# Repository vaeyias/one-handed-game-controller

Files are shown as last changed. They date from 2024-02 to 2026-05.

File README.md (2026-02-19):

![Offical github repo (PCBs are here)] https://github.com/MIT-Assistive-Technology/one-handed-game-controller
# :video_game: **One-Handed Game Controller (Left-Handed)**

## 🛠️ **Tools and Materials**
- 3D Printer
- Soldering Kit
- 1 Arduino Micro 
- 2 Thumb Joysticks (KY-023)
- 16 Two-Pin Buttons
- Electrical Wire Cables
- PLA
- 1 ¾ in machine screws size 2-56
- (optional) Foam tape

## :memo: **Instructions**
1. Download ___ files
2. 3D print ___ files
4. Print PCB
5. Solder
6. Upload code to the Arduino
7. Assemble
8. TO DO

## :mag_right: Problem Statement
**Modern game controllers do not accommodate for one-handed users.**

After a stroke or injury, a person may lose some function in their body. Recreational products for the public are often made with the assumption that a person has full control of their body, which means that after permanent injuries, a person may become limited in their choice of hobbies.

Our codesigner, Susan Bibbins, suffers from chronic pain from fibromyalgia and has limited function in her right hand. She always wanted to play video games; however, modern controllers do not accomodate one-handed users.

Our team aims to develop a comfortable and accessible game controller designed specifically for one-handed users so that our codesigner can finally play video games that she has always wanted to try.

## 🔗 References




## ✍️ Acknowledgements
To be completed

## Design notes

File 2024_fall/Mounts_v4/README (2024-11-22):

Updated top mount holes and fixed thinned out bottom mount.

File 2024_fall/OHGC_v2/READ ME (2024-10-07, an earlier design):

This version has complete front and back of OHGC. Has threaded screw holes, back finger indents, and curved edges.

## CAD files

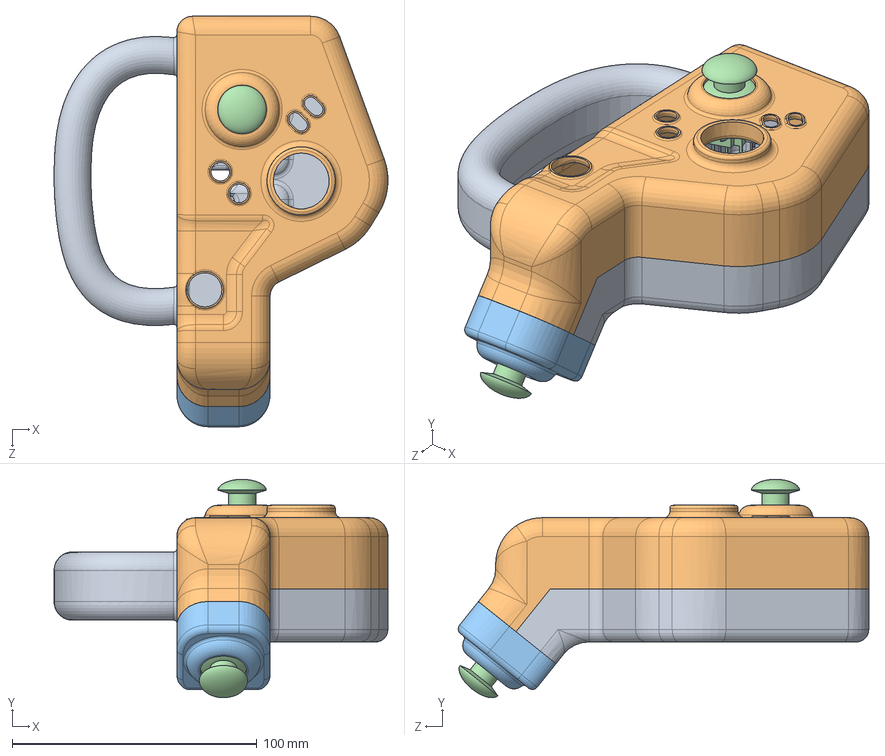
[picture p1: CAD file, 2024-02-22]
2024_spring/solidworks_designs/OHGC_assembly.SLDASM
136.4 x 89.2 x 167.7 mm
OHGC_back
OHGC_front
OHGC_bottom

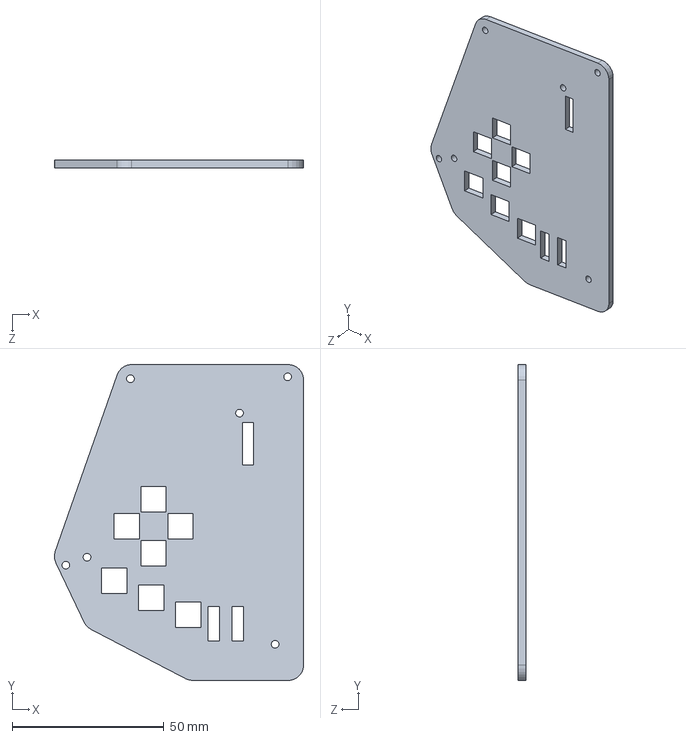
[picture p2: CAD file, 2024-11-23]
2024_fall/OHGC_2.3/Mounts_v4F_Back_Mount_v4.SLDPRT
82.1 x 104.1 x 2.54 mm

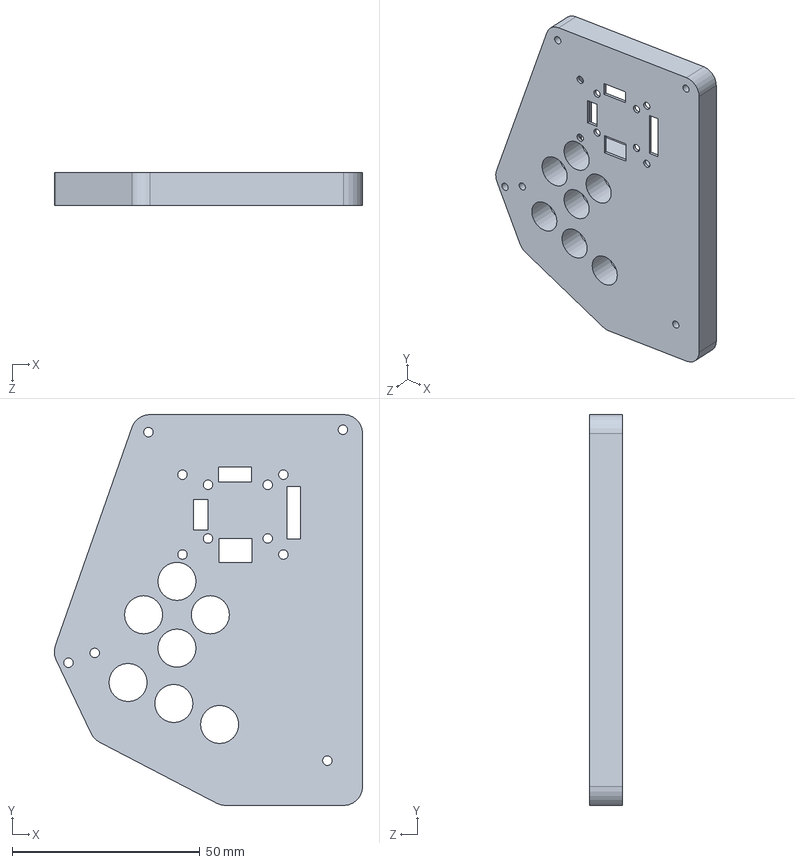
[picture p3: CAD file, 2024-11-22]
2024_fall/OHGC_v2.3/Mounts_v4/F_Front_Mount_v4.SLDPRT
82.1 x 104.1 x 8.89 mm

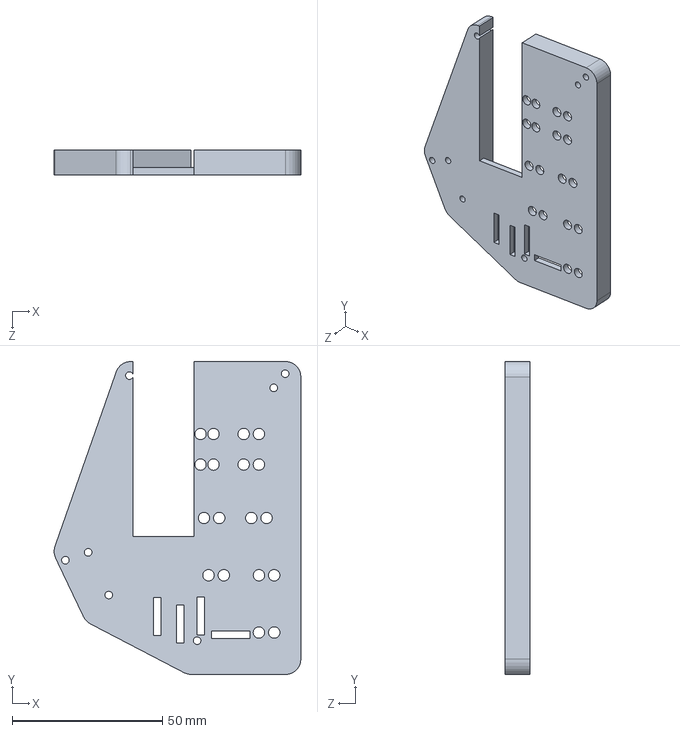
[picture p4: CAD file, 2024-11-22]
2024_fall/OHGC_v2.3/Mounts_v4B_Front_Mount_v4.SLDPRT
82.1 x 104.1 x 8.38 mm

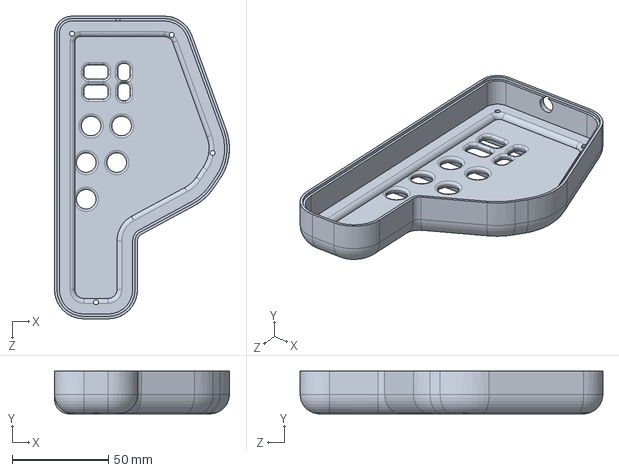
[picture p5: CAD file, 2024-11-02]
2024_fall/PCB Order 3/bottompcb.SLDPRT
91.0 x 22.2 x 157.5 mm

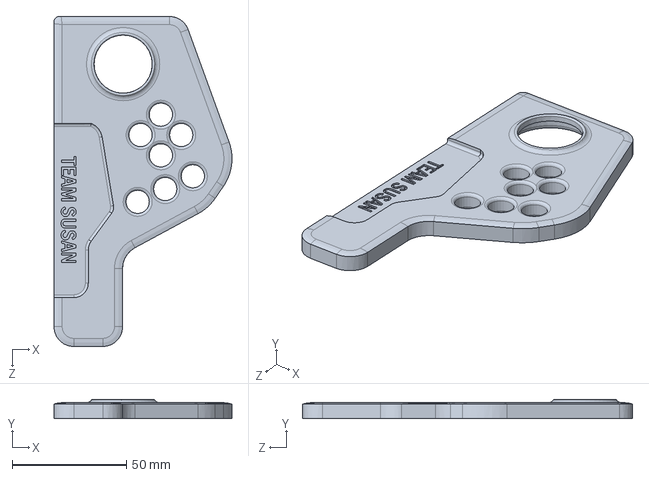
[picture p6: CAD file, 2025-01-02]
2024_fall/Showcase/Reprinted OHGC FRONT for Showcase.SLDPRT
77.8 x 8.45 x 144.3 mm

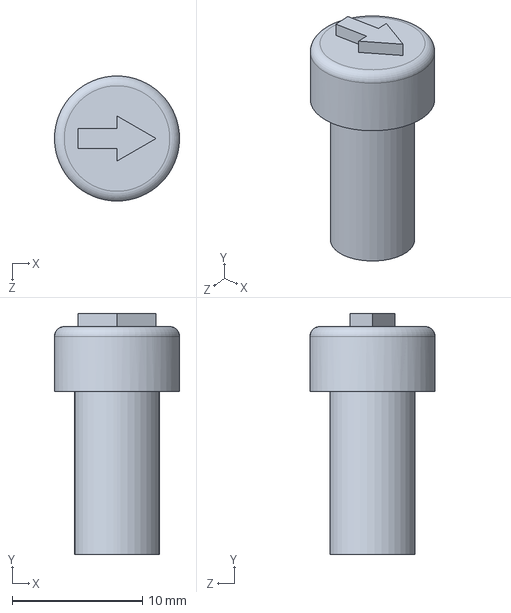
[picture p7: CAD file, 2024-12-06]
2024_spring/solidworks_designs/Button_Updated/DPADbutton.v3.SLDPRT
9.60 x 18.5 x 9.60 mm

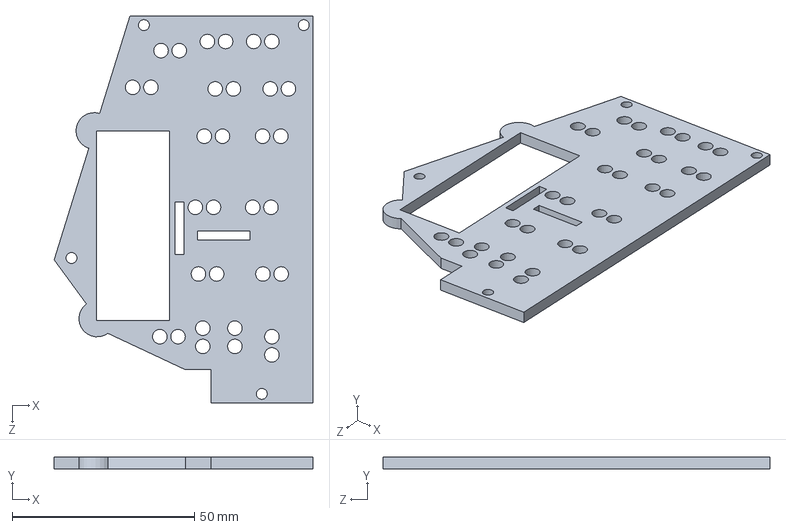
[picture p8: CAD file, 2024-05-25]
2024_spring/solidworks_designs/Mount_Updated_4-28-24.SLDPRT
71.0 x 3.17 x 106.2 mm

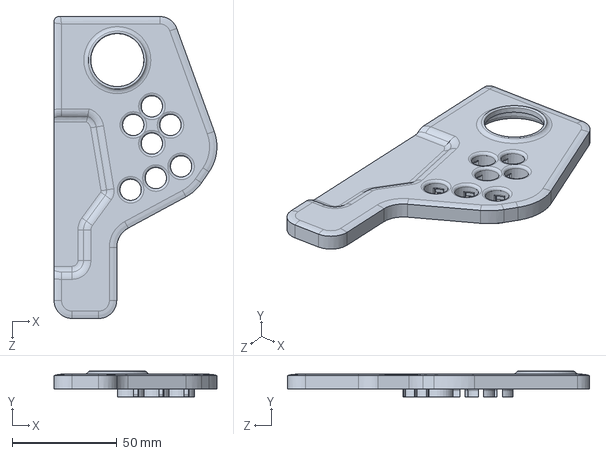
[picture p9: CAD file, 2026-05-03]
2026_spring/SLDPRT-Files/Front_Face.SLDPRT
77.8 x 12.3 x 144.3 mm

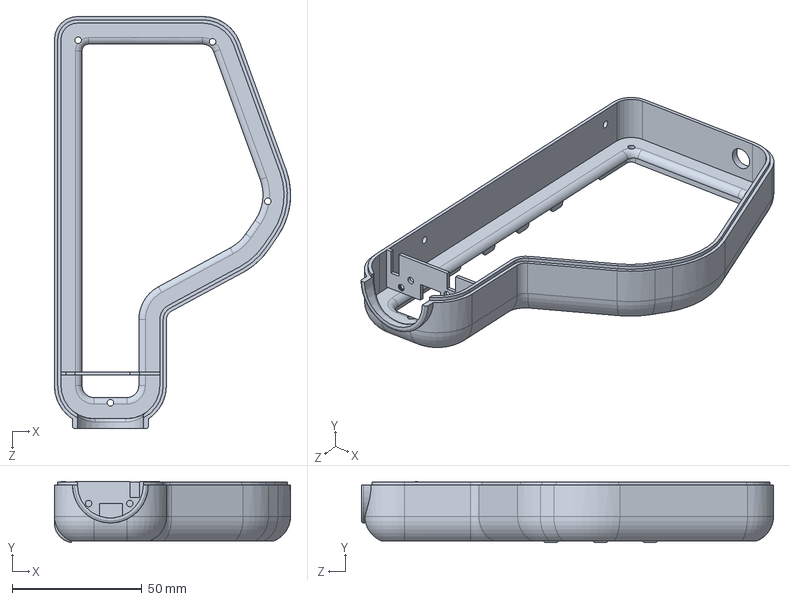
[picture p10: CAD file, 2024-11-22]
2024_fall/OHGC_v2.3/OHGC_BOTTOM_SIDEv2.3.SLDPRT
91.0 x 23.6 x 158.8 mm

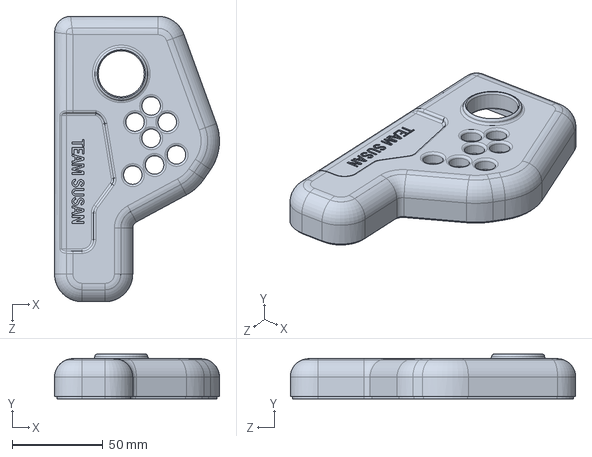
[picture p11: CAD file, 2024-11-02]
2024_fall/PCB Order 3/front_pcb.SLDPRT
91.0 x 24.8 x 157.5 mm

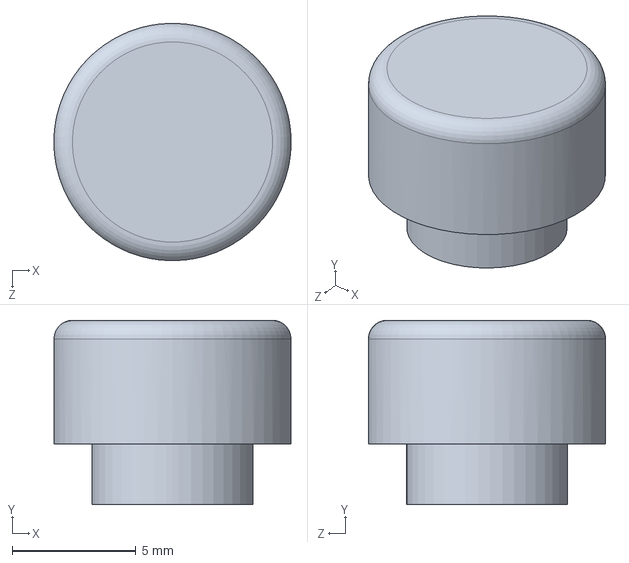
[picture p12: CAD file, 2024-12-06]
2024_spring/solidworks_designs/Button_Updated/bottom_button.v2.5.SLDPRT
9.59 x 7.46 x 9.60 mm

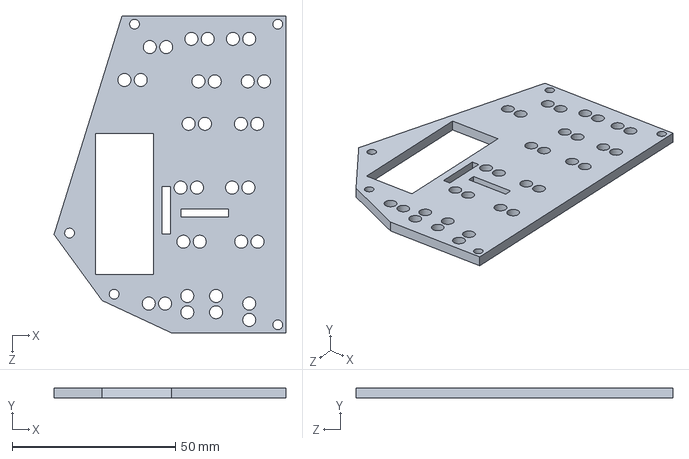
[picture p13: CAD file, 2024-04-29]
2024_spring/solidworks_designs/Mount_Updated_4-26-24.SLDPRT
71.0 x 3.17 x 97.0 mm

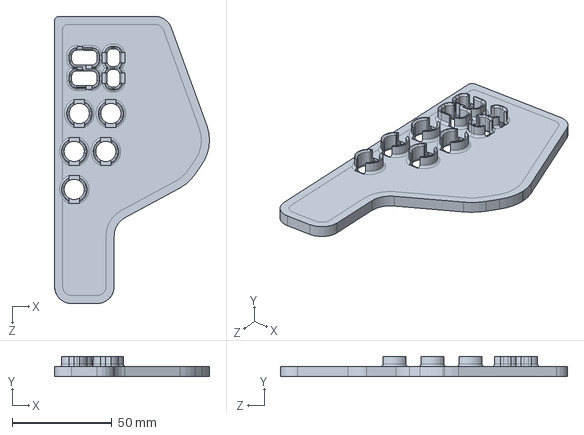
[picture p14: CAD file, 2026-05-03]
2026_spring/SLDPRT-Files/Back_Face.SLDPRT
77.8 x 10.2 x 144.3 mm

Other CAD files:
OHGC-Open-Source-Files/OHGC-SLDPRT-Files/Front_Face.SLDPRT
OHGC-Open-Source-Files/OHGC-STL-Files/F_Back_Mount_v4.1.STL
2024_fall/OHGC_v2.3/Mounts_v4/B_Back_Mount_v4.SLDPRT
2024_fall/Showcase/OHGC_BOTTOM_SIDEv2.4 FINAL.SLDPRT
2024_fall/OHGC_v1/Buttons/DPadButton_v1.SLDPRT
2024_fall/OHGC_v1/Buttons/HomeButton_v1.SLDPRT
2024_fall/OHGC_v1/Buttons/OvalButton_v1.SLDPRT
2024_fall/OHGC_v1/Buttons/PlayButton_v1.SLDPRT
2024_fall/OHGC_v1/Buttons/SelectButton_v1.SLDPRT
2024_fall/OHGC_v1/Mounts/MountPrint1.SLDPRT
2024_fall/OHGC_v1/Mounts/bottom_mount.v1.SLDPRT
2024_fall/OHGC_v1/Mounts/bottom_mount.v2.SLDPRT
2024_fall/OHGC_v1/OHGC BACK.SLDPRT
2024_fall/OHGC_v1/OHGC BACK.STL
2024_fall/OHGC_v1/OHGC BASE_SKETCH.SLDPRT
2024_fall/OHGC_v1/OHGC FRONT.SLDPRT
2024_fall/OHGC_v1/OHGC_BOTTOM_SIDE.SLDPRT
2024_fall/OHGC_v1/OHGC_BOTTOM_SIDE.STL
2024_fall/OHGC_v1/OHGC_FRONT_SIDE.SLDPRT
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

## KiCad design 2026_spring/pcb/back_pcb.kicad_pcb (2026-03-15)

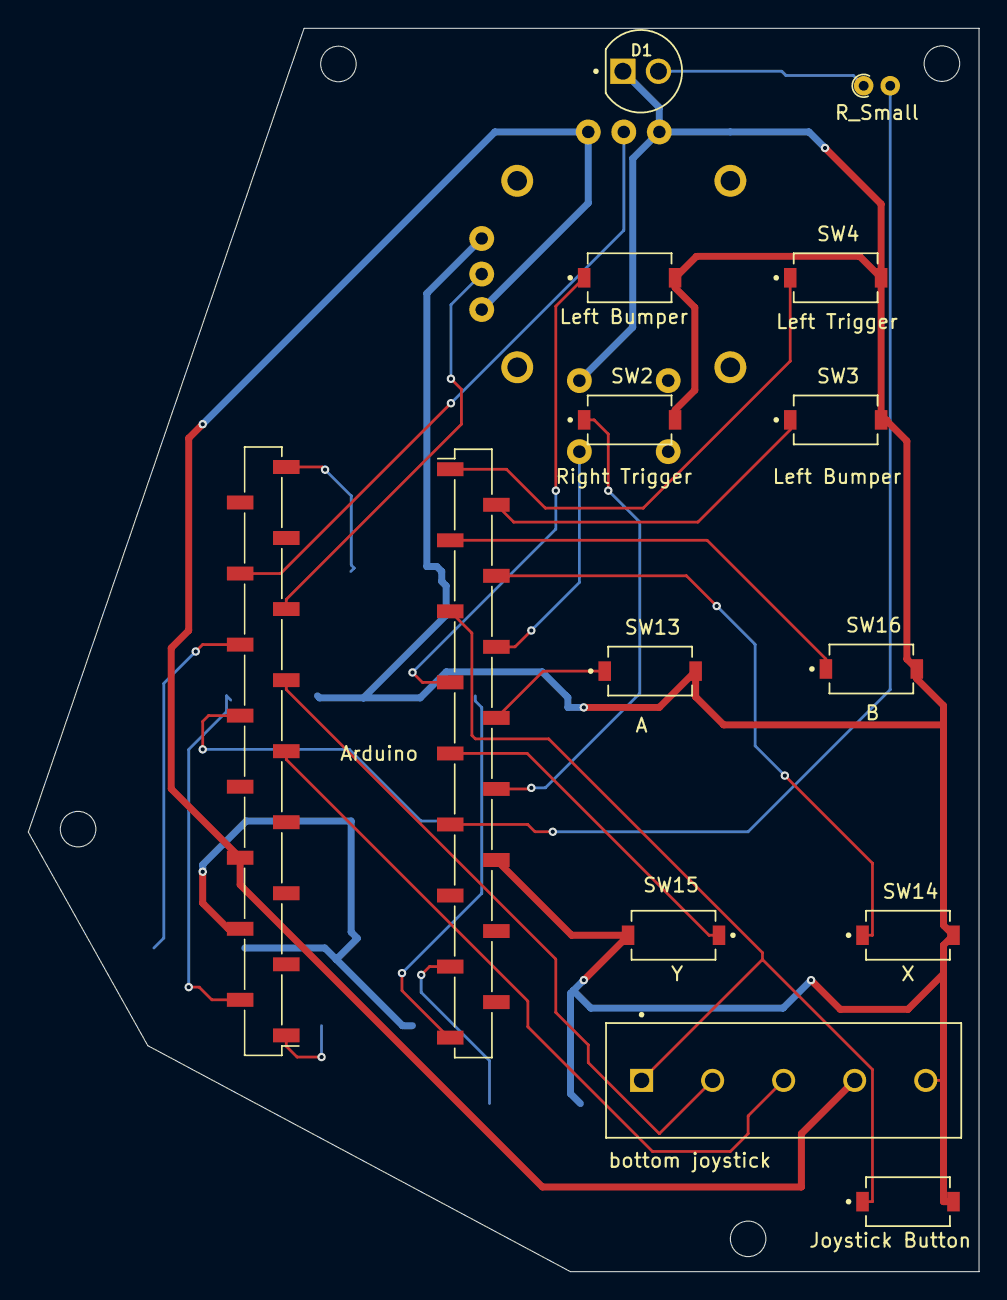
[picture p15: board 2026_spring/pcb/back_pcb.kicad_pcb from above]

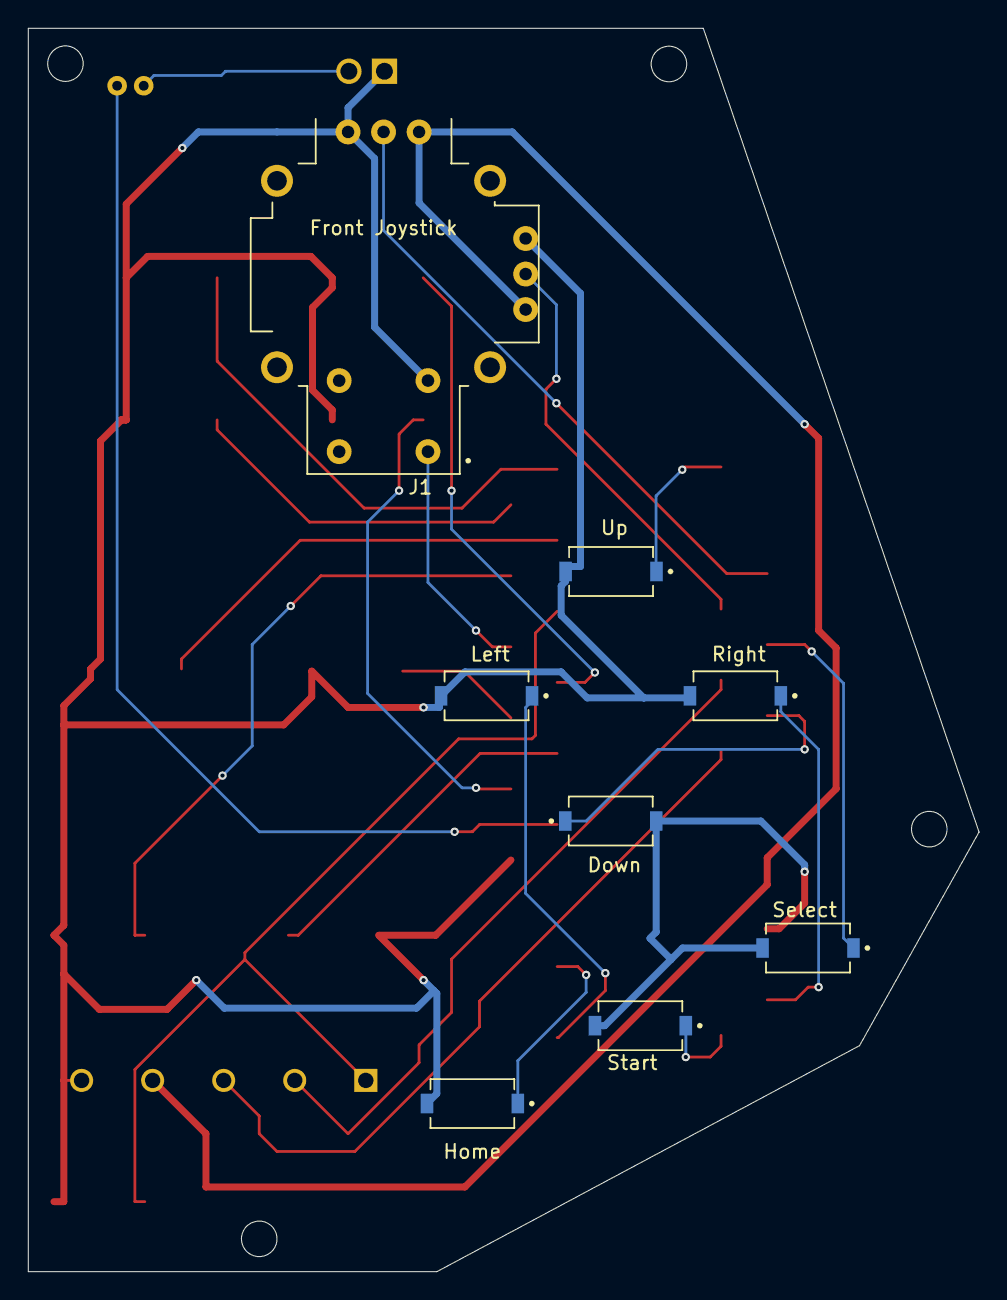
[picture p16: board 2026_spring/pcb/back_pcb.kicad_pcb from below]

Board: 2 copper layers, 68.0 x 88.9 mm, 22 parts (8 on the bottom side), 27 nets.

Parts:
D1: LED; LEDRD254W57D500H1070
J1: Front Joystick; XDCR_COM-09032
J2: bottom joystick; TE_282837-5
J3, J4: Arduino; PinSocket_1x17_P2.54mm_Vertical_SMD_Pin1Left
R1: R_Small; R_Axial_DIN0204_L3.6mm_D1.6mm_P1.90mm_Vertical
SW1: Left Trigger; SW_PTS636_SM43J_SMTR_LFS
SW2: Right Trigger; SW_PTS636_SM43J_SMTR_LFS
SW3, SW4: Left Bumper; SW_PTS636_SM43J_SMTR_LFS
SW5: Up; SW_PTS636_SM43J_SMTR_LFS
SW6: Down; SW_PTS636_SM43J_SMTR_LFS
SW8: Right; SW_PTS636_SM43J_SMTR_LFS
SW9: Left; SW_PTS636_SM43J_SMTR_LFS
SW10: Home; SW_PTS636_SM43J_SMTR_LFS
SW11: Start; SW_PTS636_SM43J_SMTR_LFS
SW13: A; SW_PTS636_SM43J_SMTR_LFS
SW14: X; SW_PTS636_SM43J_SMTR_LFS
SW15: Y; SW_PTS636_SM43J_SMTR_LFS
SW16: B; SW_PTS636_SM43J_SMTR_LFS
SW17: Select; SW_PTS636_SM43J_SMTR_LFS
joy_SW: Joystick Button; SW_PTS636_SM43J_SMTR_LFS

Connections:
/A0: J1.H2, J4.14
/A1: J1.V2, J4.13
/A2: J4.12, SW17.1
/A3: J2.2, J4.11
/A4: J4.10, SW6.1
/A5: J2.3, J4.9
/D1: J3.15, SW10.1
/D2: J3.11, R1.2
/D3: J3.10, SW2.1
/D4: J3.9, SW15.1
/D5: J3.8, SW13.1
/D6: J3.7, SW1.1
/D7: J1.B1A, J3.6
/D8: J2.1, J3.5, joy_SW.1
/D9: J3.4, SW14.1
/D10: J3.3, SW16.1
/D11: J3.2, SW3.1
/D12: J3.1, SW4.1
/D13: J4.17, SW5.1
/D14: J4.2, SW8.1
/D15: J4.1, SW11.1
/D16: J3.17, SW9.1
/GND: D1.GND, J1.B2A, J1.H3, J1.V3, J2.5, J3.12, J4.4, SW1.2, SW2.2, SW3.2, SW4.2, SW5.2, SW6.2, SW8.2, SW9.2, SW10.2, SW11.2, SW13.2, SW14.2, SW15.2, SW16.2, SW17.2, joy_SW.2
/NC: J4.7, J4.8
/R1: D1.R1, R1.1
/RST: J3.13, J4.5
/VCC: J1.H1, J1.V1, J2.4, J4.6

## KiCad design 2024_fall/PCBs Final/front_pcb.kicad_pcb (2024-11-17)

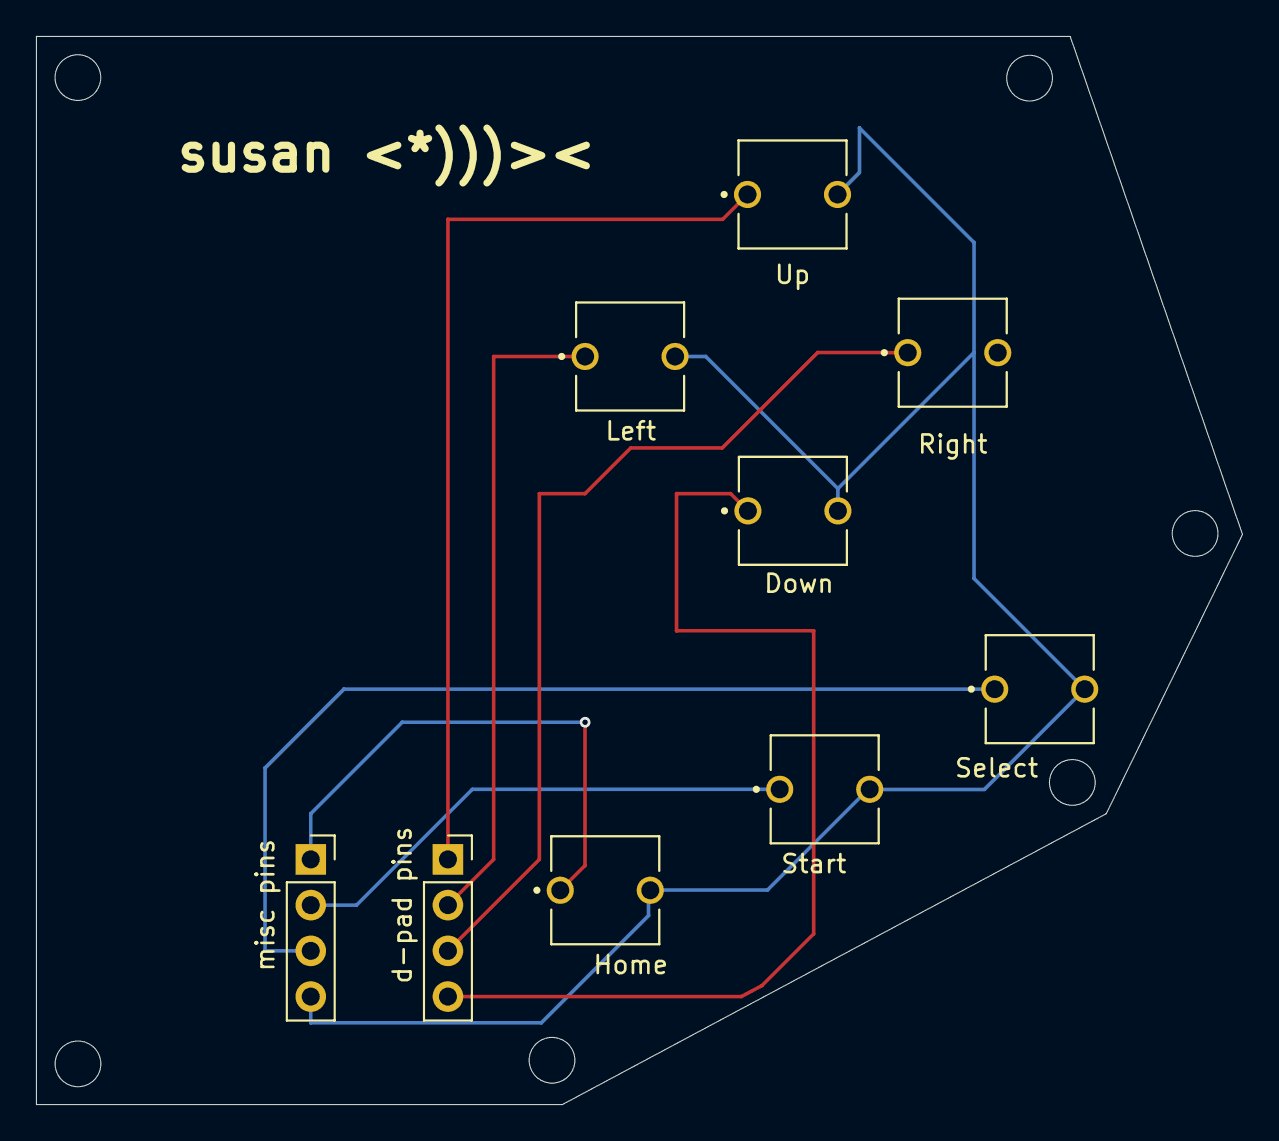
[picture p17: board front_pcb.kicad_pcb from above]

Board: 2 copper layers, 67.0 x 59.3 mm, 9 parts (0 on the bottom side), 8 nets.

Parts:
J1: d-pad pins; PinSocket_1x04_P2.54mm_Vertical
J2: misc pins; PinSocket_1x04_P2.54mm_Vertical
SW1: Up; SW_BUTT-2
SW2: Down; SW_BUTT-2
SW3: Left; SW_BUTT-2
SW4: Right; SW_BUTT-2
SW6: Home; SW_BUTT-2
SW7: Start; SW_BUTT-2
SW8: Select; SW_BUTT-2

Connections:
/D0: J1.1, SW1.1
/D1: J2.3, SW8.1
/D2: J1.2, SW3.1
/D3: J1.3, SW4.1
/D4: J1.4, SW2.1
/D16: J2.1, SW6.1
/D17: J2.2, SW7.1
/GND: J2.4, SW1.2, SW2.2, SW3.2, SW4.2, SW6.2, SW7.2, SW8.2

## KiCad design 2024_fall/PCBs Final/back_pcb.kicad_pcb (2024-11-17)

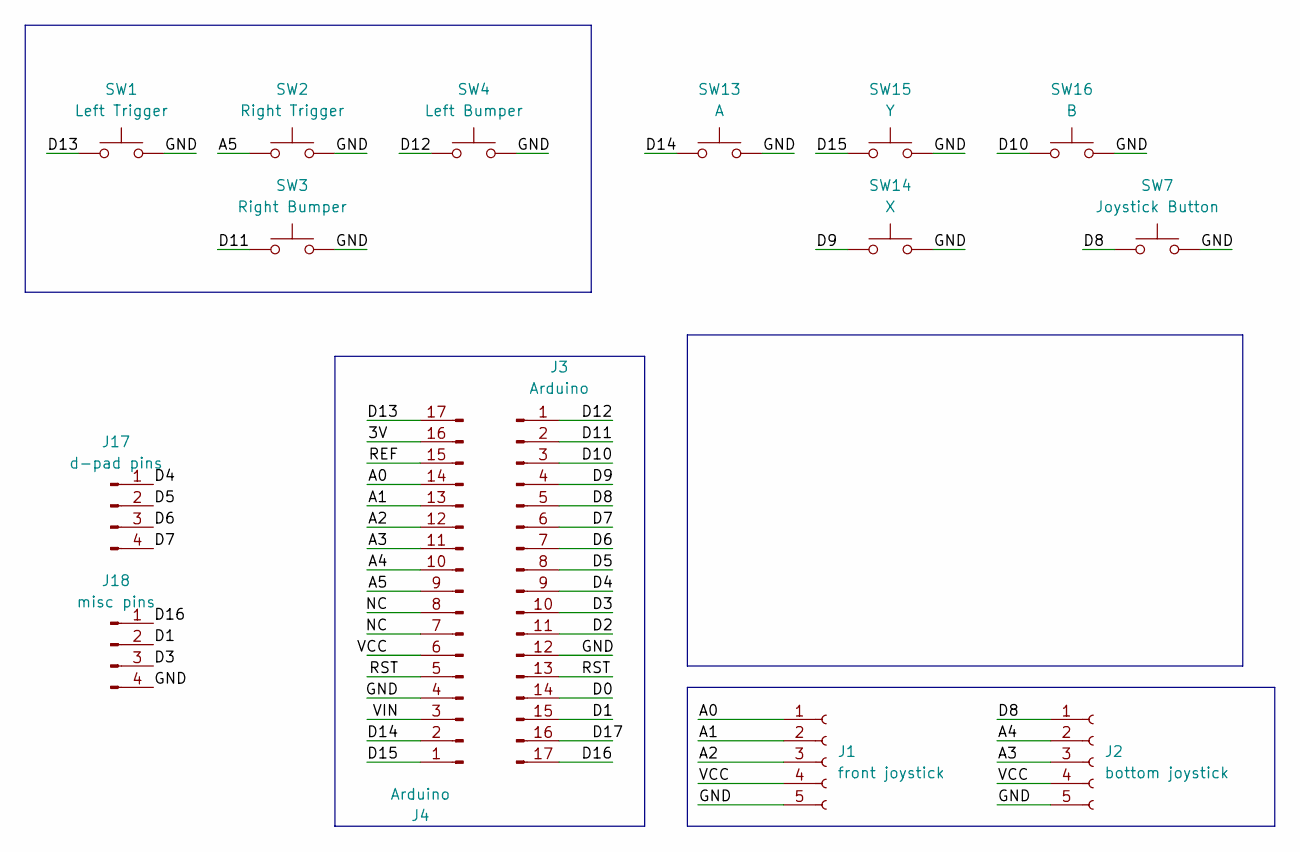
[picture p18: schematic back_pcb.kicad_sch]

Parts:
J1: front joystick; PinSocket_1x05_P2.54mm_Vertical
J2: bottom joystick; PinSocket_1x05_P2.54mm_Vertical
J3, J4: Arduino; PinSocket_1x17_P2.54mm_Vertical
J17: d-pad pins; PinSocket_1x04_P2.54mm_Vertical
J18: misc pins; PinSocket_1x04_P2.54mm_Vertical
SW1: Left Trigger; SW_BUTT-2
SW2: Right Trigger; SW_BUTT-2
SW3: Right Bumper; SW_BUTT-2
SW4: Left Bumper; SW_BUTT-2
SW7: Joystick Button; SW_BUTT-2
SW13: A; SW_BUTT-2
SW14: X; SW_BUTT-2
SW15: Y; SW_BUTT-2
SW16: B; SW_BUTT-2

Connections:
/3V: J4.16
/A0: J1.1, J4.14
/A1: J1.2, J4.13
/A2: J1.3, J4.12
/A3: J2.3, J4.11
/A4: J2.2, J4.10
/A5: J4.9, SW2.1
/D0: J3.14
/D1: J3.15, J18.2
/D2: J3.11
/D3: J3.10, J18.3
/D4: J3.9, J17.1
/D5: J3.8, J17.2
/D6: J3.7, J17.3
/D7: J3.6, J17.4
/D8: J2.1, J3.5, SW7.1
/D9: J3.4, SW14.1
/D10: J3.3, SW16.1
/D11: J3.2, SW3.1
/D12: J3.1, SW4.1
/D13: J4.17, SW1.1
/D14: J4.2, SW13.1
/D15: J4.1, SW15.1
/D16: J3.17, J18.1
/D17: J3.16
/GND: J1.5, J2.5, J3.12, J4.4, J18.4, SW1.2, SW2.2, SW3.2, SW4.2, SW7.2, SW13.2, SW14.2, SW15.2, SW16.2
/NC: J4.7, J4.8
/REF: J4.15
/RST: J3.13, J4.5
/VCC: J1.4, J2.4, J4.6
/VIN: J4.3

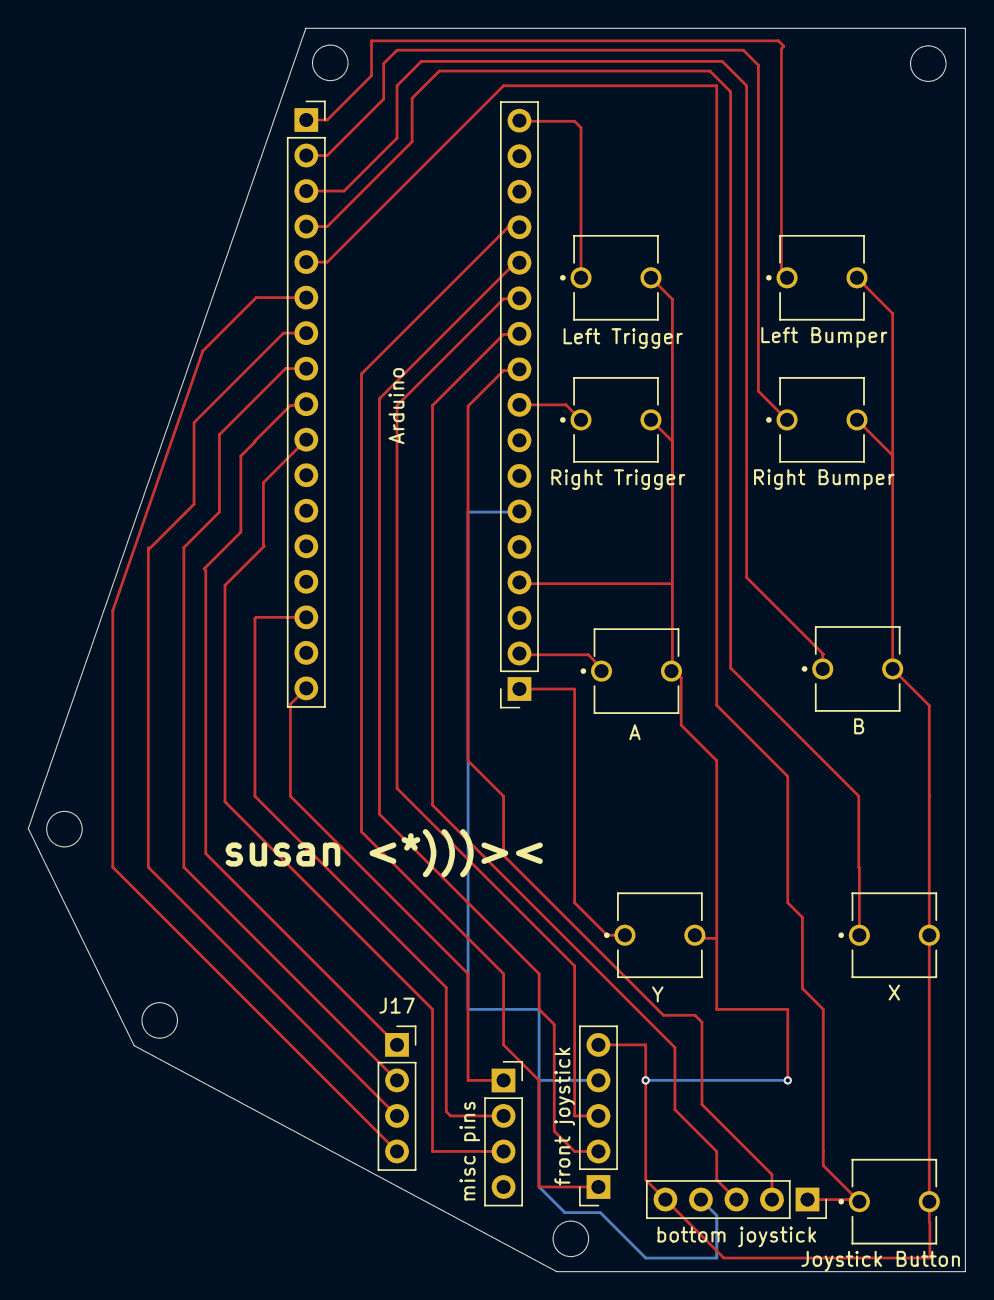
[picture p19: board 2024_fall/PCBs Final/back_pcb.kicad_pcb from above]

Board: 2 copper layers, 67.0 x 88.9 mm, 15 parts (0 on the bottom side), 25 nets.

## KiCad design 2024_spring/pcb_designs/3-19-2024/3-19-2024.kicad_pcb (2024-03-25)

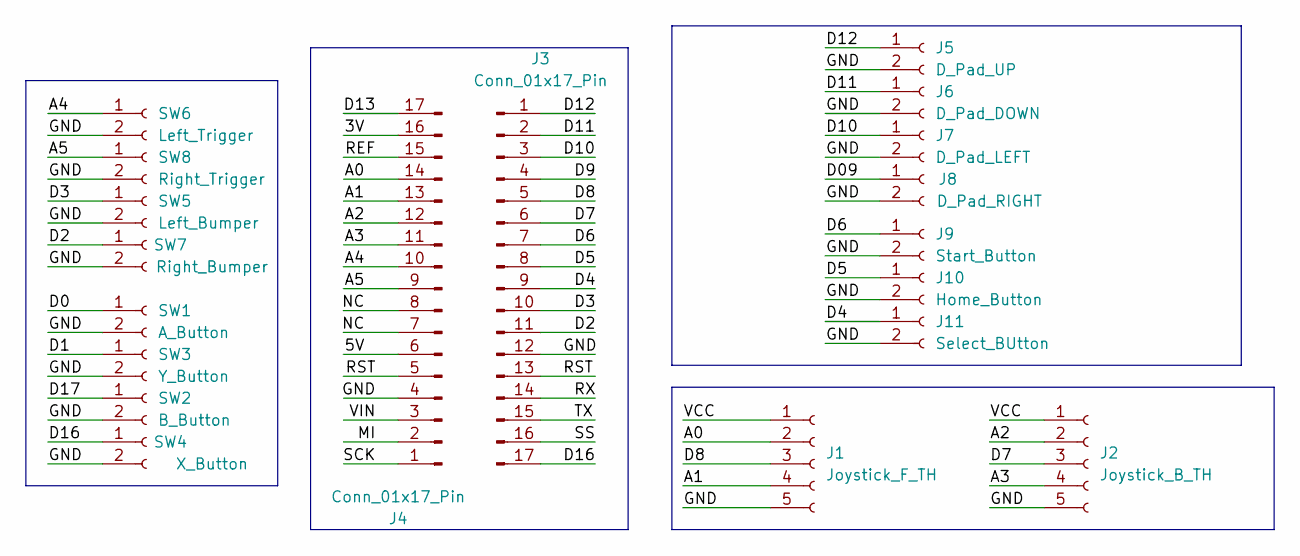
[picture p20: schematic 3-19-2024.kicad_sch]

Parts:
J1: Joystick_F_TH; SolderWire-0.1sqmm_1x05_P3.6mm_D0.4mm_OD1mm
J2: Joystick_B_TH; SolderWire-0.1sqmm_1x05_P3.6mm_D0.4mm_OD1mm
J3, J4: Conn_01x17_Pin; PinSocket_1x17_P2.54mm_Vertical
J5: D_Pad_UP; SolderWire-0.1sqmm_1x02_P3.6mm_D0.4mm_OD1mm
J6: D_Pad_DOWN; SolderWire-0.1sqmm_1x02_P3.6mm_D0.4mm_OD1mm
J7: D_Pad_LEFT; SolderWire-0.1sqmm_1x02_P3.6mm_D0.4mm_OD1mm
J8: D_Pad_RIGHT; SolderWire-0.1sqmm_1x02_P3.6mm_D0.4mm_OD1mm
J9: Start_Button; SolderWire-0.1sqmm_1x02_P3.6mm_D0.4mm_OD1mm
J10: Home_Button; SolderWire-0.1sqmm_1x02_P3.6mm_D0.4mm_OD1mm
J11: Select_BUtton; SolderWire-0.1sqmm_1x02_P3.6mm_D0.4mm_OD1mm
SW1: A_Button; SolderWire-0.1sqmm_1x02_P3.6mm_D0.4mm_OD1mm
SW2: B_Button; SolderWire-0.1sqmm_1x02_P3.6mm_D0.4mm_OD1mm
SW3: Y_Button; SolderWire-0.1sqmm_1x02_P3.6mm_D0.4mm_OD1mm
SW4: X_Button; SolderWire-0.1sqmm_1x02_P3.6mm_D0.4mm_OD1mm
SW5: Left_Bumper; SolderWire-0.1sqmm_1x02_P3.6mm_D0.4mm_OD1mm
SW6: Left_Trigger; SolderWire-0.1sqmm_1x02_P3.6mm_D0.4mm_OD1mm
SW7: Right_Bumper; SolderWire-0.1sqmm_1x02_P3.6mm_D0.4mm_OD1mm
SW8: Right_Trigger; SolderWire-0.1sqmm_1x02_P3.6mm_D0.4mm_OD1mm

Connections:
/3V: J4.16
/5V: J4.6
/A0: J1.2, J4.14
/A1: J1.4, J4.13
/A2: J2.2, J4.12
/A3: J2.4, J4.11
/A4: J4.10, SW6.1
/A5: J4.9, SW8.1
/D0: SW1.1
/D1: SW3.1
/D2: J3.11, SW7.1
/D3: J3.10, SW5.1
/D4: J3.9, J11.1
/D5: J3.8, J10.1
/D6: J3.7, J9.1
/D7: J2.3, J3.6
/D8: J1.3, J3.5
/D9: J3.4
/D09: J8.1
/D10: J3.3, J7.1
/D11: J3.2, J6.1
/D12: J3.1, J5.1
/D13: J4.17
/D16: J3.17, SW4.1
/D17: SW2.1
/GND: J1.5, J2.5, J3.12, J4.4, J5.2, J6.2, J7.2, J8.2, J9.2, J10.2, J11.2, SW1.2, SW2.2, SW3.2, SW4.2, SW5.2, SW6.2, SW7.2, SW8.2
/MI: J4.2
/NC: J4.7, J4.8
/REF: J4.15
/RST: J3.13, J4.5
/RX: J3.14
/SCK: J4.1
/SS: J3.16
/TX: J3.15
/VCC: J1.1, J2.1
/VIN: J4.3

Board: 2 copper layers, 19 parts (0 on the bottom side), 21 nets, no tracks yet.

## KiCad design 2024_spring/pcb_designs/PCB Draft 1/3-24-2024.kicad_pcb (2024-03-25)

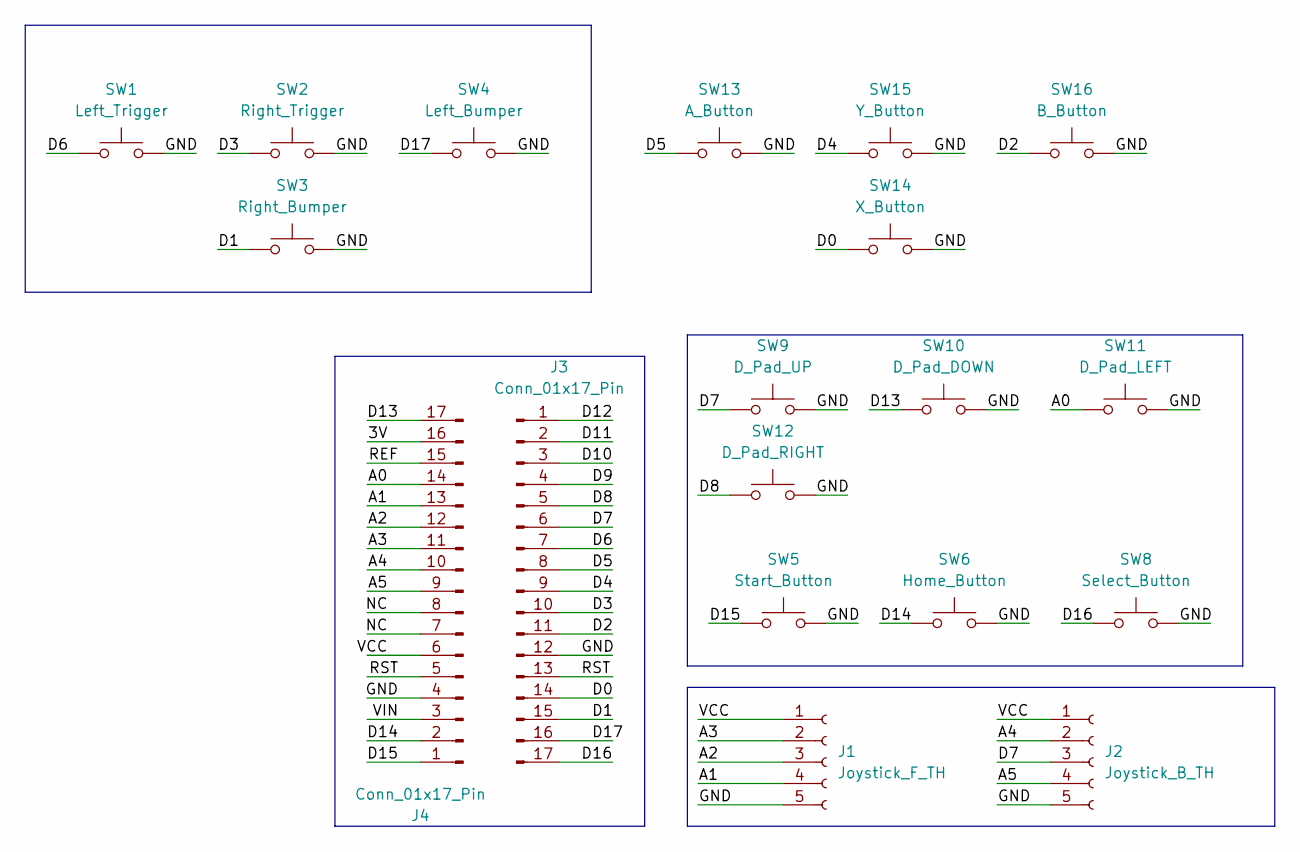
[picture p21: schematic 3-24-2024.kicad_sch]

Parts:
J1: Joystick_F_TH; PinSocket_1x05_P2.54mm_Vertical
J2: Joystick_B_TH; PinSocket_1x05_P2.54mm_Vertical
J3, J4: Conn_01x17_Pin; PinSocket_1x17_P2.54mm_Vertical
SW1: Left_Trigger; SW_BUTT-2
SW2: Right_Trigger; SW_BUTT-2
SW3: Right_Bumper; SW_BUTT-2
SW4: Left_Bumper; SW_BUTT-2
SW5: Start_Button; SW_BUTT-2
SW6: Home_Button; SW_BUTT-2
SW8: Select_Button; SW_BUTT-2
SW9: D_Pad_UP; SW_BUTT-2
SW10: D_Pad_DOWN; SW_BUTT-2
SW11: D_Pad_LEFT; SW_BUTT-2
SW12: D_Pad_RIGHT; SW_BUTT-2
SW13: A_Button; SW_BUTT-2
SW14: X_Button; SW_BUTT-2
SW15: Y_Button; SW_BUTT-2
SW16: B_Button; SW_BUTT-2

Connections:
/3V: J4.16
/A0: J4.14, SW11.1
/A1: J1.4, J4.13
/A2: J1.3, J4.12
/A3: J1.2, J4.11
/A4: J2.2, J4.10
/A5: J2.4, J4.9
/D0: J3.14, SW14.1
/D1: J3.15, SW3.1
/D2: J3.11, SW16.1
/D3: J3.10, SW2.1
/D4: J3.9, SW15.1
/D5: J3.8, SW13.1
/D6: J3.7, SW1.1
/D7: J2.3, J3.6, SW9.1
/D8: J3.5, SW12.1
/D9: J3.4
/D10: J3.3
/D11: J3.2
/D12: J3.1
/D13: J4.17, SW10.1
/D14: J4.2, SW6.1
/D15: J4.1, SW5.1
/D16: J3.17, SW8.1
/D17: J3.16, SW4.1
/GND: J1.5, J2.5, J3.12, J4.4, SW1.2, SW2.2, SW3.2, SW4.2, SW5.2, SW6.2, SW8.2, SW9.2, SW10.2, SW11.2, SW12.2, SW13.2, SW14.2, SW15.2, SW16.2
/NC: J4.7, J4.8
/REF: J4.15
/RST: J3.13, J4.5
/VCC: J1.1, J2.1, J4.6
/VIN: J4.3

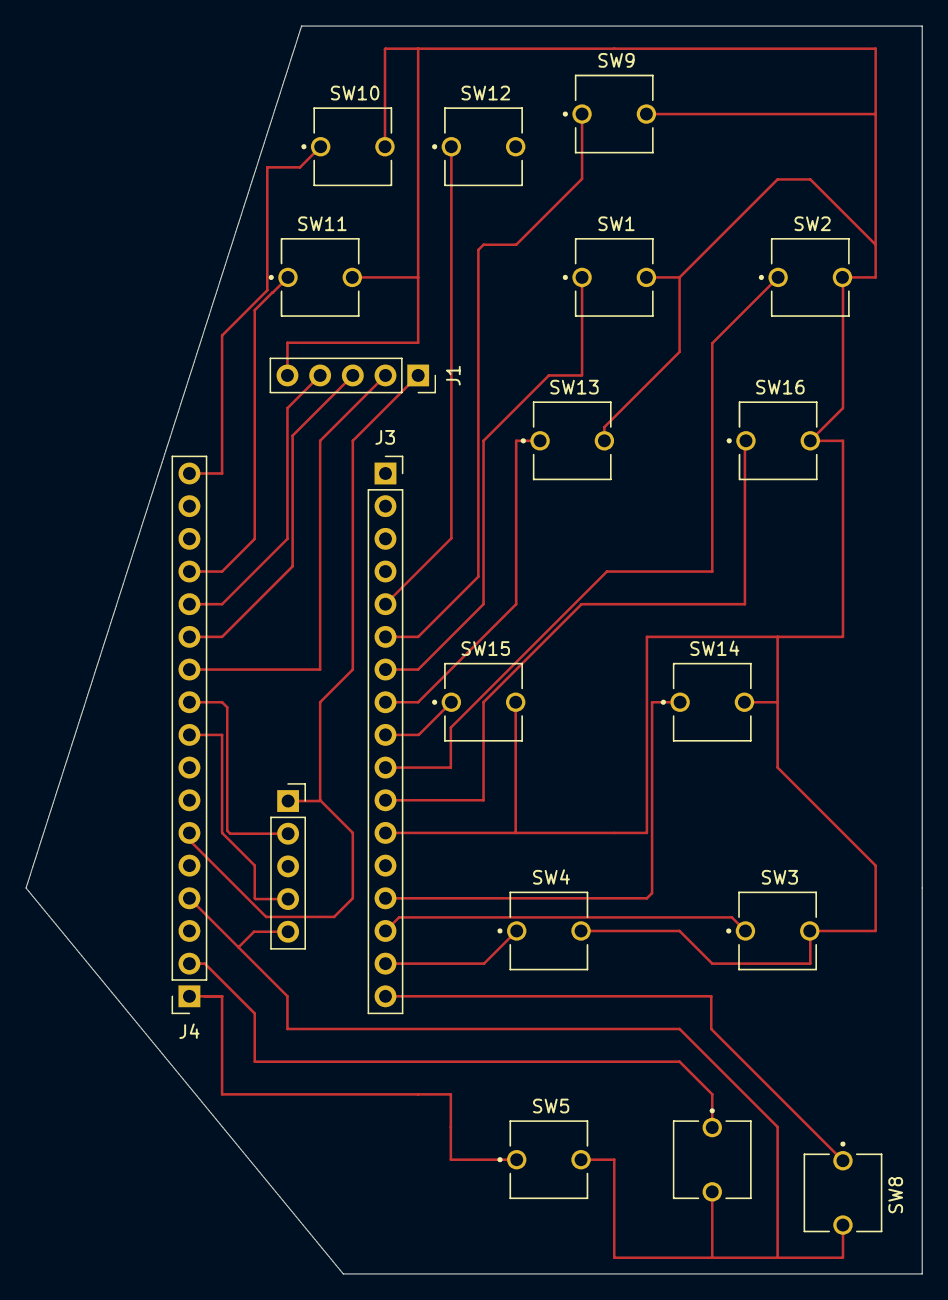
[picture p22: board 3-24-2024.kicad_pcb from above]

Board: 2 copper layers, 69.7 x 97.0 mm, 19 parts (0 on the bottom side), 24 nets.

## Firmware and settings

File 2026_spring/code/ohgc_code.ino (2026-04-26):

/*
 *  Project     Arduino XInput Library
 *  @author     David Madison
 *  @link       github.com/dmadison/ArduinoXInput
 *  @license    MIT - Copyright (c) 2019 David Madison
 *
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
 *  Example:      GamepadPins
 *  Description:  Uses all of the available pin inputs to build a 'complete'
 *                Xbox gamepad, with both analog joysticks, both triggers,
 *                and all of the main buttons.
 *
 *                * Joysticks should be your typical 10k dual potentiometers.
 *                  To prevent random values caused by floating inputs,
                    joysticks are disabled by default.
 *                * Triggers can be either analog (pots) or digital (buttons).
 *                  Set the 'TriggerButtons' variable to change between the two.
 *                * Buttons use the internal pull-ups and should be connected
 *                  directly to ground.
 *
 *                These pins are designed around the Leonardo's layout. You
 *                may need to change the pin numbers if you're using a
 *                different board type
 *
 */

#include <XInput.h>

// Setup
const boolean UseLeftJoystick   = true;  // set to true to enable left joystick
const boolean InvertLeftYAxis   = false;  // set to true to use inverted left joy Y

const boolean UseRightJoystick  = true;  // set to true to enable right joystick
const boolean InvertRightYAxis  = false;  // set to true to use inverted right joy Y

const boolean UseTriggerButtons = true;   // set to false if using analog triggers

const int ADC_Max = 1023/2;  // 10 bit

// Joystick Pins
const int Pin_LeftJoyX  = A0;
const int Pin_LeftJoyY  = A1;
const int Pin_RightJoyX = A3;
const int Pin_RightJoyY = A5;

// Trigger Pins
const int Pin_TriggerL = 6;
const int Pin_TriggerR = 3;

// Button Pins
const int Pin_ButtonA = 5;
const int Pin_ButtonB = 10;
const int Pin_ButtonX = 9;
const int Pin_ButtonY = 4;

const int Pin_ButtonLB = 12;
const int Pin_ButtonRB = 11;

const int Pin_ButtonBack = A2;
const int Pin_ButtonStart = 15;
const int Pin_ButtonLogo = 1;

// Joystick Buttons
const int Pin_ButtonL3 = 0;
const int Pin_ButtonR3 = 8;

// Directional Pad Pins
const int Pin_DpadUp    = 13;
const int Pin_DpadDown  = A4;
const int Pin_DpadLeft  = 16;
const int Pin_DpadRight = MISO;
const int LED = 2;

void setup() {
	// If using buttons for the triggers, use internal pull-up resistors
	if (UseTriggerButtons == true) {
		pinMode(Pin_TriggerL, INPUT_PULLUP);
		pinMode(Pin_TriggerR, INPUT_PULLUP);
	}
	// If using potentiometers for the triggers, set range
	else {
		XInput.setTriggerRange(0, ADC_Max);
	}

	// Set buttons as inputs, using internal pull-up resistors
	pinMode(Pin_ButtonA, INPUT_PULLUP);
	pinMode(Pin_ButtonB, INPUT_PULLUP);
	pinMode(Pin_ButtonX, INPUT_PULLUP);
	pinMode(Pin_ButtonY, INPUT_PULLUP);
	pinMode(LED, OUTPUT);


	pinMode(Pin_ButtonLB, INPUT_PULLUP);
	pinMode(Pin_ButtonRB, INPUT_PULLUP);

	pinMode(Pin_ButtonBack, INPUT_PULLUP);
	pinMode(Pin_ButtonStart, INPUT_PULLUP);
  pinMode(Pin_ButtonLogo, INPUT_PULLUP);

	pinMode(Pin_ButtonL3, INPUT_PULLUP);
	pinMode(Pin_ButtonR3, INPUT_PULLUP);

	pinMode(Pin_DpadUp, INPUT_PULLUP);
	pinMode(Pin_DpadDown, INPUT_PULLUP);
	pinMode(Pin_DpadLeft, INPUT_PULLUP);
	pinMode(Pin_DpadRight, INPUT_PULLUP);

	XInput.setJoystickRange(0, ADC_Max);  // Set joystick range to the ADC
	XInput.setAutoSend(false);  // Wait for all controls before sending

	XInput.begin();
}

void loop() {
	// Read pin values and store in variables
	// (Note the "!" to invert the state, because LOW = pressed)
	digitalWrite(LED, HIGH); 
	boolean buttonA = !digitalRead(Pin_ButtonA);
	boolean buttonB = !digitalRead(Pin_ButtonB);
	boolean buttonX = !digitalRead(Pin_ButtonX);
	boolean buttonY = !digitalRead(Pin_ButtonY);

	boolean buttonLB = !digitalRead(Pin_ButtonLB);
	boolean buttonRB = !digitalRead(Pin_ButtonRB);

	boolean buttonBack  = !digitalRead(Pin_ButtonBack);
	boolean buttonStart = !digitalRead(Pin_ButtonStart);
  boolean buttonLogo  = !digitalRead(Pin_ButtonLogo);

	boolean buttonL3 = !digitalRead(Pin_ButtonL3);
	boolean buttonR3 = !digitalRead(Pin_ButtonR3);

	boolean dpadUp    = !digitalRead(Pin_DpadUp);
	boolean dpadDown  = !digitalRead(Pin_DpadDown);
	boolean dpadLeft  = !digitalRead(Pin_DpadLeft);
	boolean dpadRight = !digitalRead(Pin_DpadRight);

	// Set XInput buttons
	XInput.setButton(BUTTON_A, buttonA);
	XInput.setButton(BUTTON_B, buttonB);
	XInput.setButton(BUTTON_X, buttonX);
	XInput.setButton(BUTTON_Y, buttonY);

	XInput.setButton(BUTTON_LB, buttonLB);
	XInput.setButton(BUTTON_RB, buttonRB);

	XInput.setButton(BUTTON_BACK, buttonBack);
	XInput.setButton(BUTTON_START, buttonStart);
  XInput.setButton(BUTTON_LOGO, buttonLogo);

	XInput.setButton(BUTTON_L3, buttonL3);
	XInput.setButton(BUTTON_R3, buttonR3);

	// Set XInput DPAD values
	XInput.setDpad(dpadUp, dpadDown, dpadLeft, dpadRight);

	// Set XInput trigger values
	if (UseTriggerButtons == true) {
		// Read trigger buttons
		boolean triggerLeft  = !digitalRead(Pin_TriggerL);
		boolean triggerRight = !digitalRead(Pin_TriggerR);

		// Set the triggers as if they were buttons
		XInput.setButton(TRIGGER_LEFT, triggerLeft);
		XInput.setButton(TRIGGER_RIGHT, triggerRight);
	}
	else {
		// Read trigger potentiometer values
		int triggerLeft  = analogRead(Pin_TriggerL);
		int triggerRight = analogRead(Pin_TriggerR);

		// Set the trigger values as analog
		XInput.setTrigger(TRIGGER_LEFT, triggerLeft);
		XInput.setTrigger(TRIGGER_RIGHT, triggerRight);
	}

	// Set left joystick
	if (UseLeftJoystick == true) {
		int leftJoyX = analogRead(Pin_LeftJoyX);
		int leftJoyY = analogRead(Pin_LeftJoyY);

		// White lie here... most generic joysticks are typically
		// inverted by default. If the "Invert" variable is false
		// then we'll take the opposite value with 'not' (!).
		boolean invert = !InvertLeftYAxis;

		XInput.setJoystickX(JOY_LEFT, leftJoyX-256.1);
		XInput.setJoystickY(JOY_LEFT, leftJoyY-250.8, invert);
	}

	// Set right joystick
	if (UseRightJoystick == true) {
		int rightJoyX = analogRead(Pin_RightJoyX);
		int rightJoyY = analogRead(Pin_RightJoyY);

		boolean invert = !InvertRightYAxis;

		XInput.setJoystickX(JOY_RIGHT, rightJoyX-248.2);
		XInput.setJoystickY(JOY_RIGHT, rightJoyY-260.5, invert);
	}

	// Send control data to the computer
	XInput.send();
}

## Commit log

2024-02-22 :truck: add fall23 solidworks
    [9032.SLDPRT, ButtonType1.SLDPRT, ButtonType2.SLDPRT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]
2024-03-10 :construction: add initial pcb sch
    [updated_sch.kicad_sch]
2024-03-10 Added updated PCB Layout and SCH
    [3_9_2024_PCB_Edit_pcb.kicad_pcb, 3_9_2024sch.kicad_sch]
2024-03-18 3-18-24 🚧
    Updated PCB Schematic and PCB
2024-03-19 🚧 3-19-2024
    [3-19-2024.kicad_pcb, 3-19-2024.kicad_sch]
2024-03-25 :construction: finish draft 1 of wiring
    - changed symbols to two-prong buttons
    - finished initial draft of wiring
    [3-19-2024.kicad_pcb, 3-19-2024.kicad_sch, 3-24-2024.kicad_pcb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]
2024-04-07 rewire wires to not cross
    [4-7-2024.kicad_pcb, 4-7-2024.kicad_sch]
2024-04-07 :construction: rewire ground connection
    [4-7-2024.kicad_pcb]
2024-04-08 :sparkles: finish first pcb draft
    [4-7-2024.kicad_pcb, 4-7-2024.kicad_sch]
2024-04-29 :sparkles: finish pcb draft 2
    [pcb_2.kicad_pcb, pcb_2.kicad_sch]
2024-04-29 :truck: pcb order 2 zip file
2024-05-13 update pcb draft 2 files
    [PCB_Draft_2.kicad_pcb, SCH_Draft_2.kicad_sch]
2024-05-13 remove old pcb draft 2 files
    [pcb_2.kicad_pcb, pcb_2.kicad_sch]
2024-05-25 🚗 Bottom Mount
    [Mount_Updated_4-28-24.SLDPRT, Mount_Updated_4-28-24.STL]
2024-09-22 📝 add instructions section to readme
2024-09-22 :truck: move spring 2024 files to folder
    [3-19-2024.kicad_pcb, 3-19-2024.kicad_sch, 3-24-2024.kicad_pcb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]
2024-10-06 :memo: update readme with materials
2024-10-18 Bottom Joystick Holders
    [JoystickTest.SLDPRT, Joystick_Holder_test.SLDPRT]
2024-10-25 Add files via upload
    Adjusted button positioning to fit on a PCB. Fixed palm rest fillet and added team name engraving.
    [OHGC FRONT_SIDEv2.1.2.SLDPRT, OHGC FRONTv2.1.2.SLDPRT]
2024-10-25 Rename OHGC FRONT_SIDE_FINAL.SLDPRT to OHGC FRONT_SIDEv2.1_W_HANDLEHOLE.SLDPRT
    [OHGC FRONT_SIDEv2.1_W_HANDLEHOLE.SLDPRT]
2024-10-30 :sparkles: Add PCB Draft 3
    - front pcb
    - modify bottom pcb for front pcb
    [PCB_Bottom_3.kicad_pcb, PCB_Bottom_3.kicad_sch, ohgc_front_pcb.kicad_pcb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]
2024-11-02 :sparkles: updated pcbs for new joysticks
    [PCB_Draft_2-B_Cu.gbr, PCB_Draft_2-B_Mask.gbr, PCB_Draft_2-B_Paste.gbr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]
2024-11-02 :sparkles: pcb sketches
    [bottompcb.SLDPRT, front_pcb.SLDPRT]
2024-11-03 :construction: remove joystick from front pcb
    [ohgc_front_pcb.kicad_pcb]
2024-11-14 Create Mount
    A space for Mounts
2024-11-17 :sparkles: fix dpad placement and add missing via
    [back_pcb.kicad_pcb, back_pcb.kicad_sch, front_pcb.kicad_pcb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]
2024-12-05 Create Buttons_Updated
2024-12-22 Rename Dpadbutton.v1 (1).SLDPRT to ButtonsV1
2024-12-22 Rename 2024_fall/OHGC_v1/homebutton.v1 (1) (1).SLDPRT to 2024_fall/OHGC_v1/Buttons/HomeButton_v1.SLDPRT
    [HomeButton_v1.SLDPRT]
2024-12-22 Rename ovalbutton.v1 (1) (1).SLDPRT to OvalButton_v1.SLDPRT
    [OvalButton_v1.SLDPRT]
2024-12-22 Rename playbutton.v1 (1) (1).SLDPRT to PlayButton_v1.SLDPRT
    [PlayButton_v1.SLDPRT]
2024-12-22 Rename selectbutton.v1 (1) (1).SLDPRT to SelectButton_v1.SLDPRT
    [SelectButton_v1.SLDPRT]
2024-12-22 Rename OHGC FRONT_SIDEv2.2.SLDPRT to OHGC FRONT_SIDEv2.2.SLDPRT
    [OHGC FRONT_SIDEv2.2.SLDPRT]
2024-12-22 Rename OHGC FRONTv2.2.SLDPRT to OHGC FRONTv2.2.SLDPRT
    [OHGC FRONTv2.2.SLDPRT]
2024-12-25 Rename OHGC FRONTv2.2.SLDPRT to OHGC FRONTv2.3.SLDPRT
    [OHGC FRONTv2.3.SLDPRT]
2024-12-25 Create OHGC-STL-Files
2024-12-30 Rename F_Back_Mount_v4.1.STL to Top-Front Mount.STL
    [Top-Front Mount.STL]
2024-12-30 Rename F_Front_Mount_v4.1.STL to Top-Back Mount.STL
    [Top-Back Mount.STL]
2024-12-30 Rename OHGC_BOTTOMv2.2.STL to Back Face.STL
    [Back Face.STL]
2024-12-30 Rename Back Face.STL to BackFace.STL
    [BackFace.STL]
2024-12-30 Rename Top-Back Mount.STL to Top-BackMount.STL
    [Top-BackMount.STL]
2024-12-30 Rename Top-Front Mount.STL to Top-Front_Mount.STL
    [Top-Front_Mount.STL]
2026-03-05 :sparkle: merge front and back pcb
    [back_pcb.kicad_pcb, back_pcb.kicad_sch]
2026-03-05 fix back pcb labels
    [back_pcb.kicad_pcb]
2026-03-08 :construction: fix screw terminals
    [back_pcb.kicad_pcb, back_pcb.kicad_sch]
2026-03-13 Rename Front_Side .SLDPRT to Front_Side.SLDPRT
    [Front_Side.SLDPRT]
2026-03-15 :sparkle: move arduino to middle of pcb
    [back_pcb.kicad_pcb, back_pcb.kicad_sch]
2026-03-15 Rename Front_Side (2).SLDPRT to Front_Side.SLDPRT
    [Front_Side.SLDPRT]
2026-03-19 add pcb order zip file
2026-04-02 Updated holes on Front and Back Side to match Handle
    [Back_Side.SLDPRT, Front_Side.SLDPRT, Handle.SLDPRT]
2026-04-07 Adjusted Handle brass insert hole diameter
    [Handle.SLDPRT]
2026-04-19 Added holes for brass inserts
    [Back_Face.SLDPRT, Back_Side.SLDPRT, Front_Face.SLDPRT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]
2026-04-24 Added Posts for Brass Inserts
    [Back_Side.SLDPRT, Front_Face.SLDPRT, Front_Side.SLDPRT]
2026-04-26 Updated Back/Front Sides & Faces
    Increased Back Side holes for posts
    Removed post from Back Side
    Removed screw hole from Front Side
    Increased diameter of Front Face Slots for Screw Head
    Removed holes from Back Face
    [Back_Face.SLDPRT, Back_Side.SLDPRT, Front_Face.SLDPRT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]
